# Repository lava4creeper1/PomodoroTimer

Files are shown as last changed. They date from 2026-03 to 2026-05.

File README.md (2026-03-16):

# Pomodoro Timer

This project is intended to create an arduino controlled timer which implements the pomodoro technique, to help with studying. Achieving this will require electrical, software and mechanical design, the requirements for each of which are listed below.

##  Requirements - Electrical
- The device shall run on an Arduino Nano microcontroller and utilise no more GPIO pins than are available to it
- The device shall contain a seven segment display capable of displaying a countdown
- The device shall contain an LED to visually alert a user when the timer expires
- The device shall contain a buzzer to auditorily alert a user when a timer expires
- The device shall contain a potentiometer capable of controlling the volume of said buzzer
- The device shall contain a vibration device to haptically alert a user when a timer expires
- The device shall contain switches to enable or disable each of these feedback devices; these switches shall be associated with an LED to indicate their state
- The device shall contain a "Begin" button and a "Reset" button to start the timer and stop timer or disable alert, respectively
- The device may, depending on the availability of GPIO pins, be capable of using extra buttons for increased functionality
- The device shall be powered via commonly available household batteries, such as AA or AAA

## Requirements - Software - Incomplete
- TBC

## Requirements - Mechanical - Incomplete
- TBC

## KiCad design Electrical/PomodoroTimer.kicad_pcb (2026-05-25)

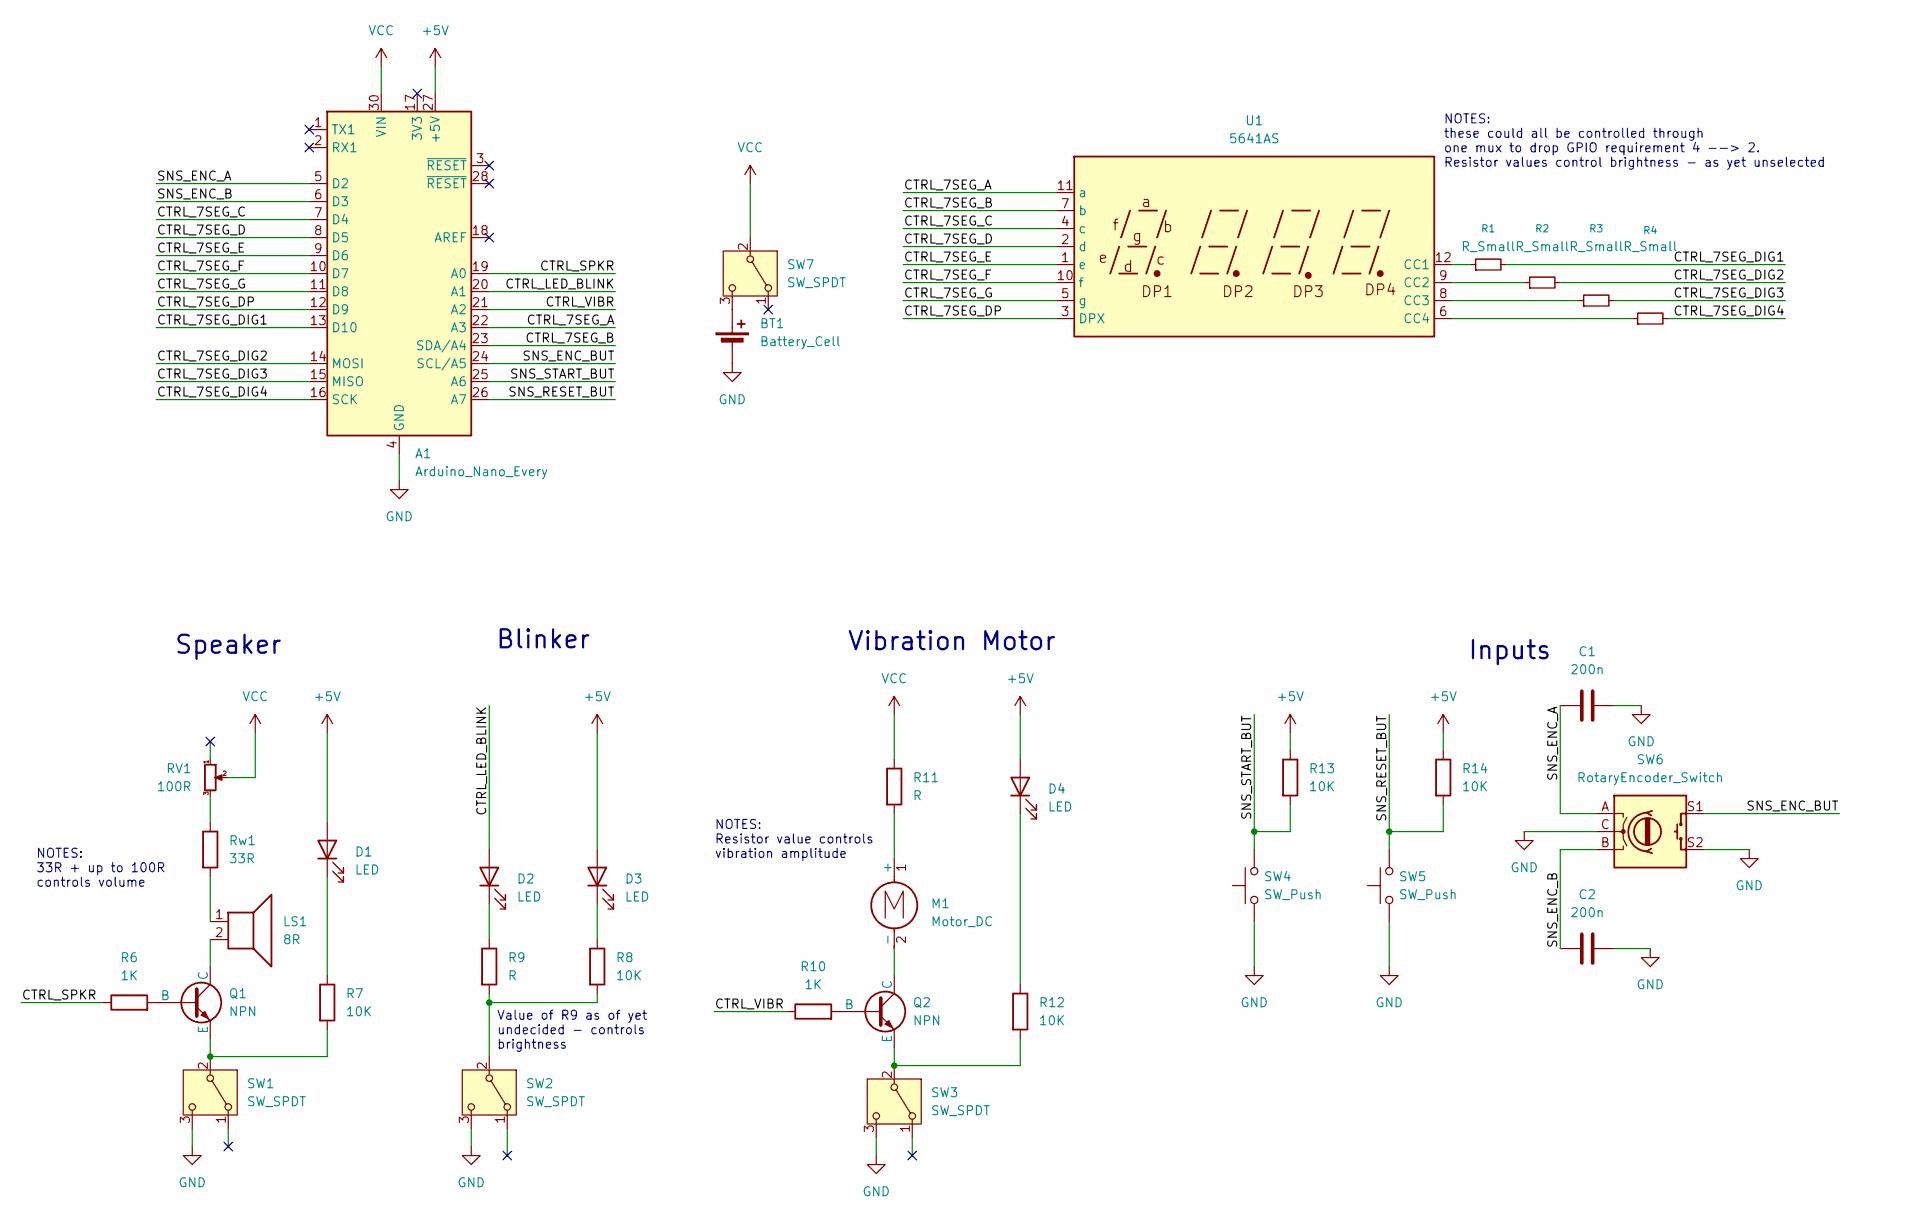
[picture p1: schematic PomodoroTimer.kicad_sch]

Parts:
A1: Arduino_Nano_Every; Arduino_Nano
BT1: Battery_Cell; PinHeader_1x02_P2.54mm_Horizontal
C1, C2: 200n; C_Axial_L3.8mm_D2.6mm_P10.00mm_Horizontal
D1, D2, D3, D4: LED; LED_D2.0mm_W4.8mm_H2.5mm_FlatTop
LS1: 8R; PinHeader_1x02_P2.54mm_Horizontal
M1: Motor_DC; PinHeader_1x02_P2.54mm_Horizontal
Q1, Q2: NPN; PinHeader_1x03_P2.54mm_Vertical
R1, R2, R3, R4: R_Small; R_Axial_DIN0207_L6.3mm_D2.5mm_P10.16mm_Horizontal
R6, R10: 1K; R_Axial_DIN0207_L6.3mm_D2.5mm_P10.16mm_Horizontal
R7, R8, R12, R13, R14: 10K; R_Axial_DIN0207_L6.3mm_D2.5mm_P10.16mm_Horizontal
R9, R11: R; R_Axial_DIN0207_L6.3mm_D2.5mm_P10.16mm_Horizontal
RV1: 100R; PinHeader_1x03_P2.54mm_Vertical
Rw1: 33R; R_Axial_DIN0207_L6.3mm_D2.5mm_P10.16mm_Horizontal
SW1, SW2, SW3, SW7: SW_SPDT; PinHeader_1x03_P2.54mm_Vertical
SW4, SW5: SW_Push; SW_SPST_Omron_B3F-40xx
SW6: RotaryEncoder_Switch; RotaryEncoder_Alps_EC11E-Switch_Vertical_H20mm
U1: 5641AS; CA56-12SURKWA

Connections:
+5V: A1.27 (+5V), D1.2 (A), D3.2 (A), D4.2 (A), R13.1, R14.1
/CTRL_7SEG_A: A1.22 (A3), U1.11 (a)
/CTRL_7SEG_B: A1.23 (SDA/A4), U1.7 (b)
/CTRL_7SEG_C: A1.7 (D4), U1.4 (c)
/CTRL_7SEG_D: A1.8 (D5), U1.2 (d)
/CTRL_7SEG_DIG1: A1.13 (D10), R1.2
/CTRL_7SEG_DIG2: A1.14 (MOSI), R2.2
/CTRL_7SEG_DIG3: A1.15 (MISO), R3.2
/CTRL_7SEG_DIG4: A1.16 (SCK), R4.2
/CTRL_7SEG_DP: A1.12 (D9), U1.3 (DPX)
/CTRL_7SEG_E: A1.9 (D6), U1.1 (e)
/CTRL_7SEG_F: A1.10 (D7), U1.10 (f)
/CTRL_7SEG_G: A1.11 (D8), U1.5 (g)
/CTRL_LED_BLINK: A1.20 (A1), D2.2 (A)
/CTRL_SPKR: A1.19 (A0), R6.1
/CTRL_VIBR: A1.21 (A2), R10.1
/SNS_ENC_A: A1.5 (D2), C1.1, SW6.A
/SNS_ENC_B: A1.6 (D3), C2.1, SW6.B
/SNS_ENC_BUT: A1.24 (SCL/A5), SW6.S1
/SNS_RESET_BUT: A1.26 (A7), R14.2, SW5.2
/SNS_START_BUT: A1.25 (A6), R13.2, SW4.2
GND: A1.4 (GND), A1.29 (GND), BT1.2 (-), C1.2, C2.2, SW1.3 (C), SW2.3 (C), SW3.3 (C), SW4.1, SW5.1, SW6.C, SW6.S2
unnamed: BT1.1 (+), SW7.3 (C)
unnamed: D1.1 (K), R7.1
unnamed: D2.1 (K), R9.1
unnamed: D3.1 (K), R8.1
unnamed: D4.1 (K), R12.1
unnamed: LS1.1, Rw1.2
unnamed: M1.1 (+), R11.2
unnamed: M1.2 (-), Q2.1 (C)
unnamed: Q1.2 (B), R6.2
unnamed: LS1.2, Q1.1 (C)
unnamed: Q1.3 (E), R7.2, SW1.2 (B)
unnamed: Q2.2 (B), R10.2
unnamed: Q2.3 (E), R12.2, SW3.2 (B)
unnamed: RV1.3, Rw1.1
unnamed: R8.2, R9.2, SW2.2 (B)
unnamed: R1.1, U1.12 (CC1)
unnamed: R2.1, U1.9 (CC2)
unnamed: R3.1, U1.8 (CC3)
unnamed: R4.1, U1.6 (CC4)
VCC: A1.30 (VIN), R11.1, RV1.2, SW7.2 (B)

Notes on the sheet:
Vibration Motor
Blinker
Inputs
NOTES: 33R + up to 100R controls volume
NOTES: these could all be controlled through one mux to drop GPIO requirement 4 --> 2. Resistor values control brightness - as yet unselected
Speaker
NOTES: Resistor value controls vibration amplitude
Value of R9 as of yet undecided - controls brightness

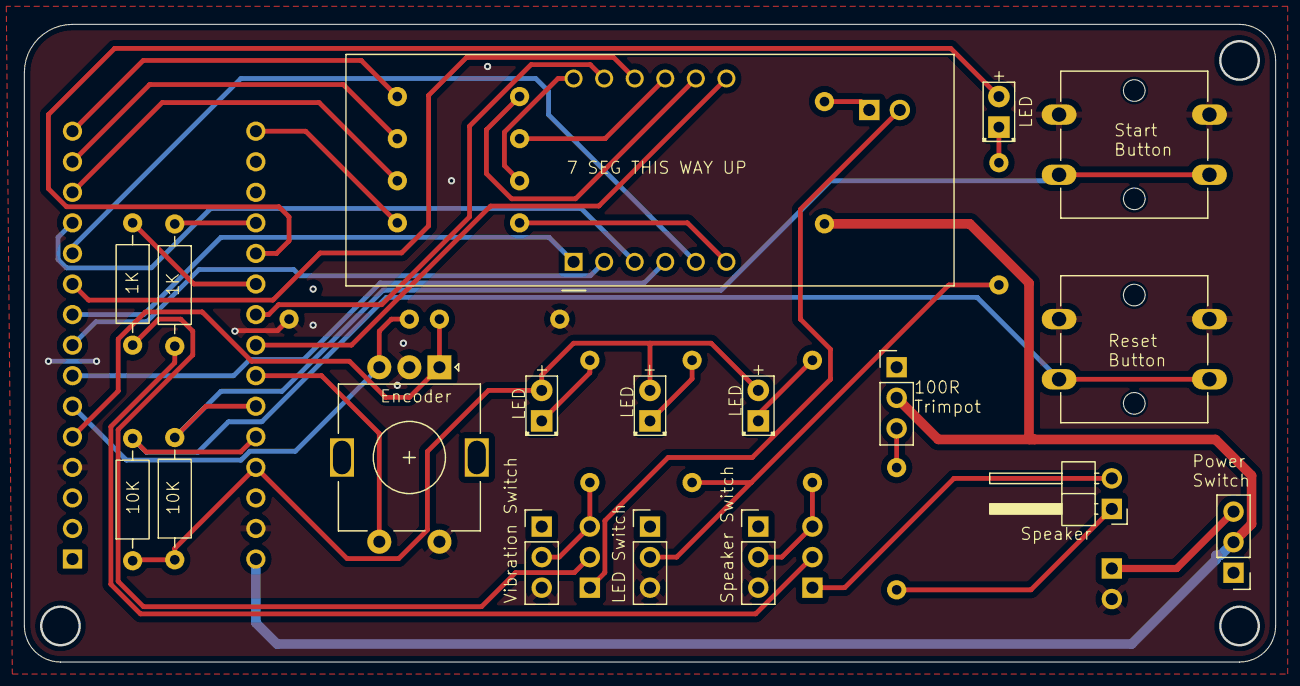
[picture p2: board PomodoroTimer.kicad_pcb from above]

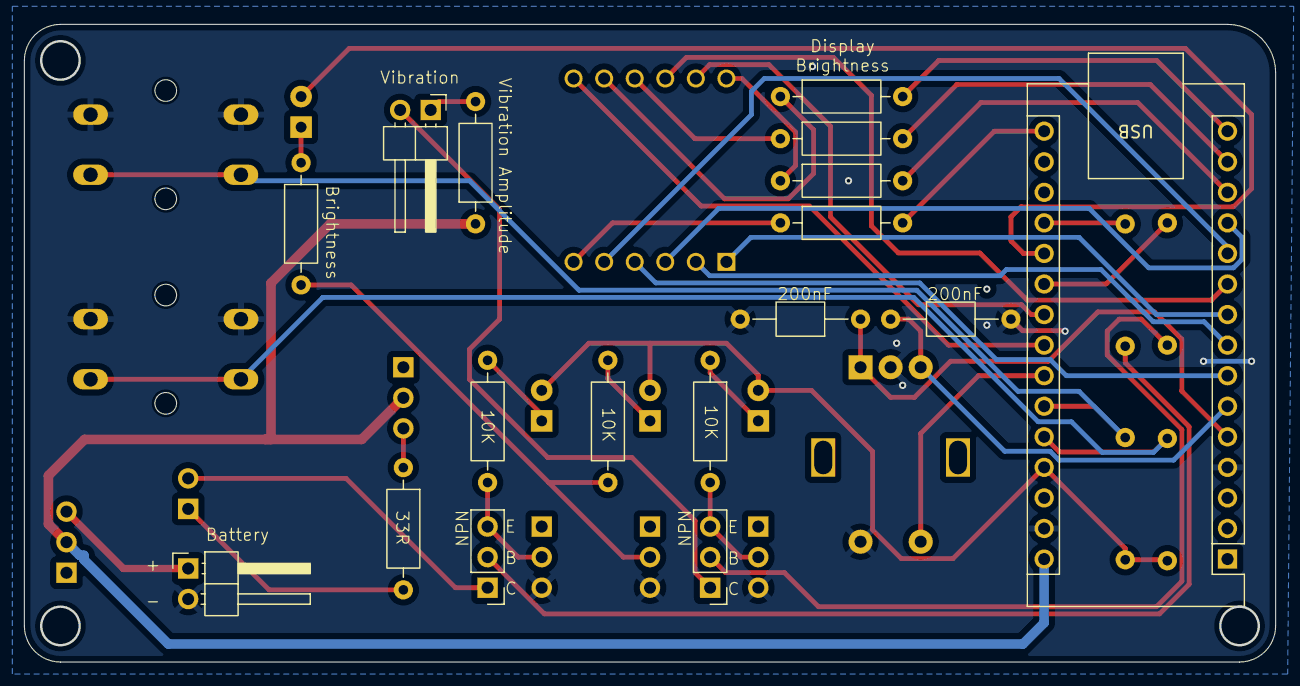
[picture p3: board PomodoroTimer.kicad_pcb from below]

Board: 2 copper layers, 104.0 x 53.0 mm, 35 parts (17 on the bottom side), 42 nets.

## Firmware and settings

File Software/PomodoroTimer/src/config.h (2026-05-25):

#pragma once

#define SNS_ENCODER_A 2
#define SNS_ENCODER_B 3
#define SNS_ENCODER_BUTTON A5
#define SNS_START_BUTTON A6
#define SNS_RESET_BUTTON A7

#define CTRL_7SEG_A A3
#define CTRL_7SEG_B A4
#define CTRL_7SEG_C 4
#define CTRL_7SEG_D 5
#define CTRL_7SEG_E 6
#define CTRL_7SEG_F 7
#define CTRL_7SEG_G 8
#define CTRL_7SEG_DP 9

#define CTRL_7SEG_DIG_1 10
#define CTRL_7SEG_DIG_2 11
#define CTRL_7SEG_DIG_3 12
#define CTRL_7SEG_DIG_4 13

#define CTRL_SPEAKER A0
#define CTRL_LED_BLINK A1
#define CTRL_VIBRATOR A2

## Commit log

2026-03-16 Added electrical schematic
    [PomodoroTimer.kicad_pcb, PomodoroTimer.kicad_sch]
2026-03-21 created schematic and pcb design for pomodoro timer
    [PomodoroTimer.kicad_pcb, PomodoroTimer.kicad_sch]
2026-05-25 Added code folder and initialised projectio project
    [PomodoroTimer-B_Cu.gbr, PomodoroTimer-B_Mask.gbr, PomodoroTimer-B_Paste.gbr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]
